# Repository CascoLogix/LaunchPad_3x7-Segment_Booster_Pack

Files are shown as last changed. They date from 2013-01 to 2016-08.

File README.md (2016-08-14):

# LaunchPad_3x7-Segment_Booster_Pack

#Description
This is just a simple 3x7-segment display that can be plugged into the TI MSP430 

#Background Info
I wanted to make my own 7-segment LED display booster pack for the LaunchPad that doesn't use a display driver IC, such as the CD4056BE, or SN7446A. In other words, I wanted to be in control of the firmware to perform driving the segments of each digit and performing the digit scanning function. 
So, I came up with this nifty little board - very simple. It includes a buffer driver IC, since the MSP430 IO pins are not rated to drive this much current in total. 
It was also a learning exercise, in that it was the first project where I used KiCAD's EDA software to learn all the ins and outs of creating schematic decals, PCB footprints, working with the component library interface, maping the schematic decals to the PCB footprints. And for the finishing touch, using Wings3D for creating the solid rendering of the boards. It was fun, easy, and it worked and I learned a lot in the process. 
Checkout the video in the links section below to see it in action!

#Links
##CascoLogix Product Page:
http://www.cascologix.com/store/p3/LaunchPad%C2%A03x7-segment_Booster_Pack.html
##Tindie Product Page:
https://www.tindie.com/products/CascoLogix/msp430-launchpad-3x7-segment-booster-pack/
##Hackaday Project Page:
https://hackaday.io/project/1779-launchpad-3x7-segment-display-booster-pack
##OSHPark PCB Page
https://oshpark.com/shared_projects/FeiOSTLi
##Video
https://www.youtube.com/watch?v=f7Dp6MClfQ0

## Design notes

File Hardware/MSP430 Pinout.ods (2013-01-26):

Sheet: MSP430F2112_28TSSOP
 | MSP430F2112IPWR
Pin# | Primary Name | Alternate Function | Signal Name
1 | TEST/SBWTCK |  | SBWTCK
2 | DVCC |  | 3.3V
3 | P2.5/Rosc/CA5
4 | DVSS |  | GND
5 | XOUT/P2.7/CA7
6 | XIN/P2.6/CA6
7 | RST/NMI/SBWTDIO |  | SBWTDIO
8 | P2.0/ACLK/A0/CA2 |  | DA_0
9 | P2.1/TAINCLK/SMCLK/A1/CA3 |  | DA_1
10 | P2.2/TA0.0/A2/CA4/CAOUT |  | DA_2
11 | P3.0/UCB0STE/UCA0CLK/A5 |  | SPI_CLK
12 | P3.1/UCB0SIMO/UCB0SDA |  | I2C_SDA
13 | P3.2/UCB0SOMI/UCB0SCL |  | I2C_SCL
14 | P3.3/UCB0CLK/UCA0STE |  | SPI_CS
15 | P3.4/UCA0TXD/UCA0SIMO |  | SPI_SIMO
16 | P3.5/UCA0RXD/UCA0SOMI |  | SPI_SOMI
17 | P3.6/TA1.0/A6
18 | P3.7/TA1.1/A7
19 | P2.3/TA0.1/A3/V /Ve /CA0
20 | P2.4/TA0.2/A4/V /Ve /CA1
21 | P1.0/TACLK/ADC10CLK/CAOUT |  | SEG_A
22 | P1.1/TA0.0/TA1.0 |  | SEG_B
23 | P1.2/TA0.1 |  | SEG_C
24 | P1.3/TA0.2 |  | SEG_D
25 | P1.4/SMCLK/TCK |  | SEG_E
26 | P1.5/TA0.0/TMS |  | SEG_F
27 | P1.6/TA0.1/TDI/TCLK |  | SEG_G
28 | P1.7/TA0.2/TDO/TDI |  | SEG_DP

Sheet: MSP430F2112_32VQFN
 | MSP430F2112IRHBR
Pin# | Primary Name | Alternate Function | Signal Name
1 | DVSS |  | GND
2 | XOUT/P2.7/CA7
3 | XIN/P2.6/CA6
4 | NC
5 | RST/NMI/SBWTDIO |  | SBWTDIO
6 | P2.0/ACLK/A0/CA2 |  | DA_0
7 | P2.1/TAINCLK/SMCLK/A1/CA3 |  | DA_1
8 | P2.2/TA0.0/A2/CA4/CAOUT |  | DA_2
9 | P3.0/UCB0STE/UCA0CLK/A5 |  | SPI_CLK
10 | P3.1/UCB0SIMO/UCB0SDA |  | I2C_SDA
11 | P3.2/UCB0SOMI/UCB0SCL |  | I2C_SCL
12 | P3.3/UCB0CLK/UCA0STE |  | SPI_CS
13 | P3.4/UCA0TXD/UCA0SIMO |  | SPI_SIMO
14 | P3.5/UCA0RXD/UCA0SOMI |  | SPI_SOMI
15 | P3.6/TA1.0/A6
16 | P3.7/TA1.1/A7
17 | NC
18 | P2.3/TA0.1/A3/V /Ve /CA0
19 | P2.4/TA0.2/A4/V /Ve /CA1
20 | NC
21 | P1.0/TACLK/ADC10CLK/CAOUT |  | SEG_A
22 | P1.1/TA0.0/TA1.0 |  | SEG_B
23 | P1.2/TA0.1 |  | SEG_C
24 | P1.3/TA0.2 |  | SEG_D
25 | P1.4/SMCLK/TCK |  | SEG_E
26 | P1.5/TA0.0/TMS |  | SEG_F
27 | P1.6/TA0.1/TDI/TCLK |  | SEG_G
28 | P1.7/TA0.2/TDO/TDI |  | SEG_DP
29 | TEST/SBWTCK |  | SBWTCK
30 | DVCC |  | 3.3V
31 | NC
32 | P2.5/R /CA5

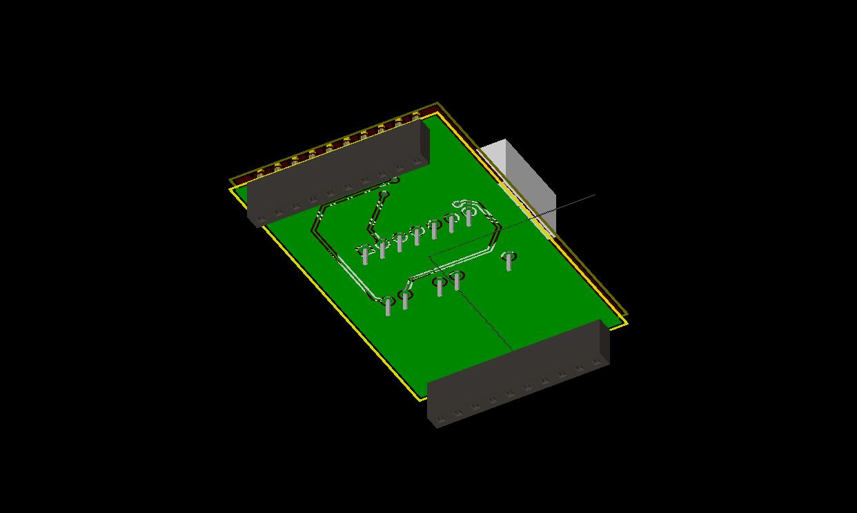
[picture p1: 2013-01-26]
Rendered_Pics/LaunchPad_3x7-Segment_Display_Booster_Pack_Isometric_Bottom.jpg

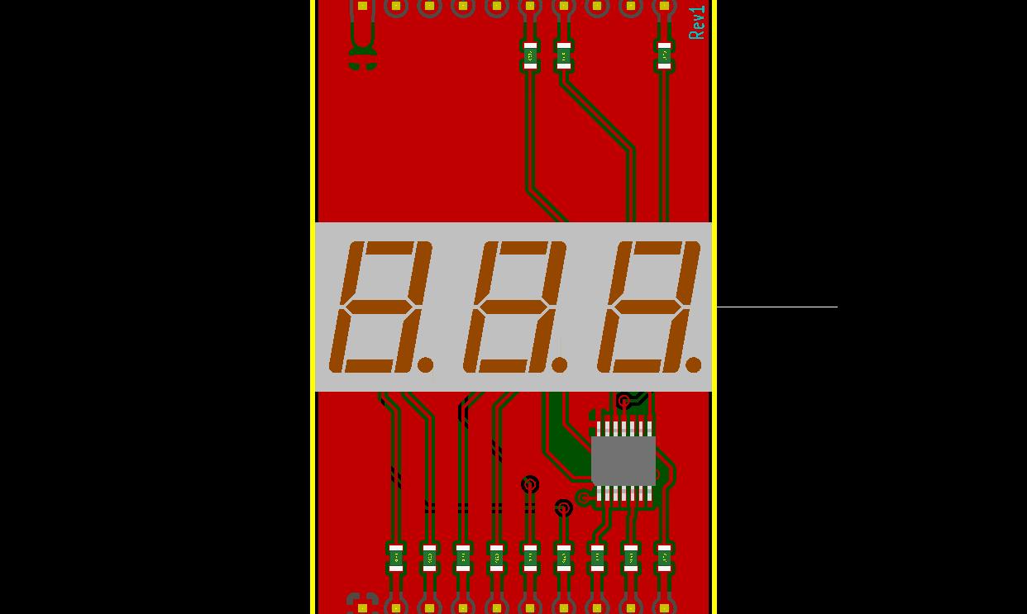
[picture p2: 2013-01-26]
Rendered_Pics/LaunchPad_3x7-Segment_Display_Booster_Pack_Top_90.jpg

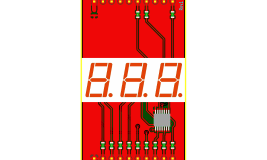
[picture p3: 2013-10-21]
Rendered_Pics/LaunchPad_3x7-Segment_Display_Booster_Pack_Top_90_Resized.png

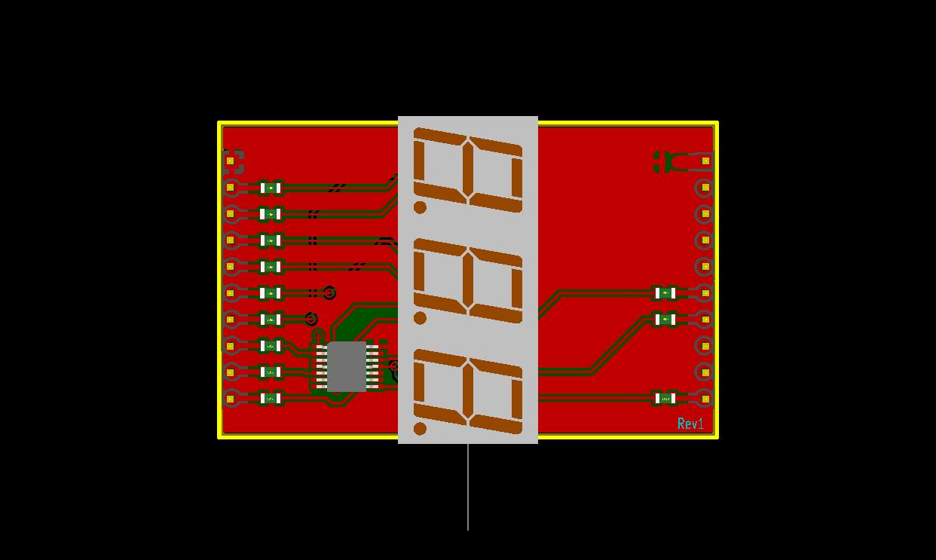
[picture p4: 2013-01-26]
Rendered_Pics/LaunchPad_3x7-Segment_Display_Booster_Pack_Top.jpg

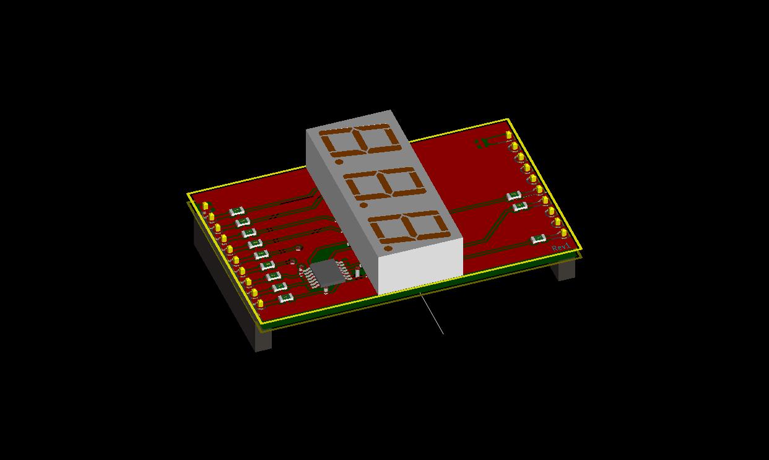
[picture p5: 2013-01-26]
Rendered_Pics/LaunchPad_3x7-Segment_Display_Booster_Pack_Isometric2.jpg

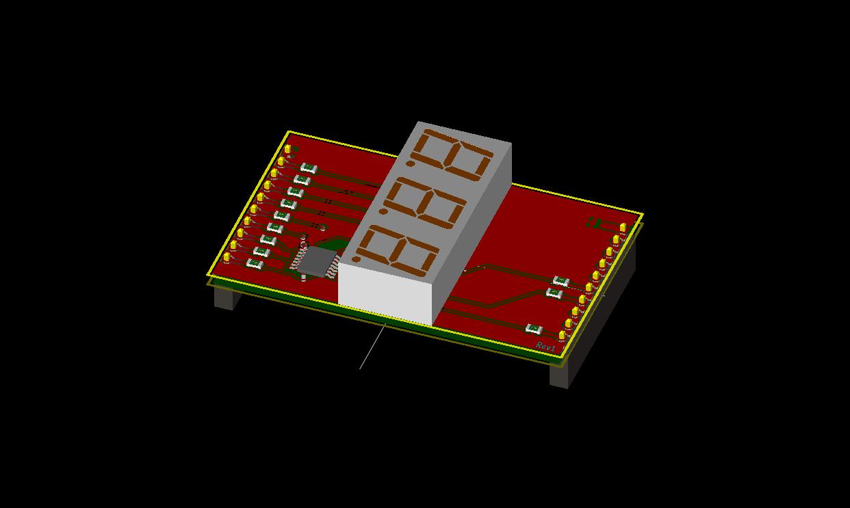
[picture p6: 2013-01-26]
Rendered_Pics/LaunchPad_3x7-Segment_Display_Booster_Pack_Isometric.jpg

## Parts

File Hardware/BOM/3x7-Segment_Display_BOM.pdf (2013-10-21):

Vendor | Vendor P/N | Mfg | Mfg P/N | Reference Designator | Qty | Description | Price Ea | Total
| | | | PCB | 1 | Printed Circuit Board | $3.80 | $3.80
Digi-Key | S7008-ND | Sullins Connector Solutions | PPTC101LFBN-RC | P1, P2 | 2 | CONN HEADER FEMALE 10POS.1" TIN | $0.83 | $1.66
Digi-Key | 568-2288-1-ND | Philips | 74LVC125APW,118 | U1 | 1 | IC BUFF DVR TRI-ST QD 14TSSOP | $0.46 | $0.46
Digi-Key | 311-100GRCT-ND | Yageo | RC0603JR-07100RL | R12,R11,R1 0,R9,R8,R7, R6,R5 | 8 | RES 100 OHM 1/10W 5% 0603 SMD | $0.01 | $0.10
Digi-Key | 311-1.0KGRCT-ND | Yageo | RC0603JR-071KL | R4,R3,R2,R 1 | 4 | RES 1.0K OHM 1/10W 5% 0603 SMD | $0.01 | $0.10
Digi-Key | 445-3448-1-ND | TDK Corporation | C1608Y5V0J106Z | C1 | 1 | CAP CER 10UF 6.3V Y5V 0603 | $0.42 | $0.42
Digi-Key | 160-1544-5-ND | Lite-On Inc | LTC-4624JR | U2 | 1 | LED 7-SEG .4" 3DGT SUPER RED CA | $3.24 | $3.24
| | | | | | | Total | $5.98

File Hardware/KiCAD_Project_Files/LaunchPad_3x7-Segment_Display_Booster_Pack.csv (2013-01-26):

ref | value | footprint
C1 | 10uF
P1 | HEADER_1X10
P2 | HEADER_1X10
R1 | RES
R2 | RES
R3 | RES
R4 | RES
R5 | RES
R6 | RES
R7 | RES
R8 | RES
R9 | RES
R10 | RES
R11 | RES
R12 | RES
U1 | 74LS125
U2 | LTC4624

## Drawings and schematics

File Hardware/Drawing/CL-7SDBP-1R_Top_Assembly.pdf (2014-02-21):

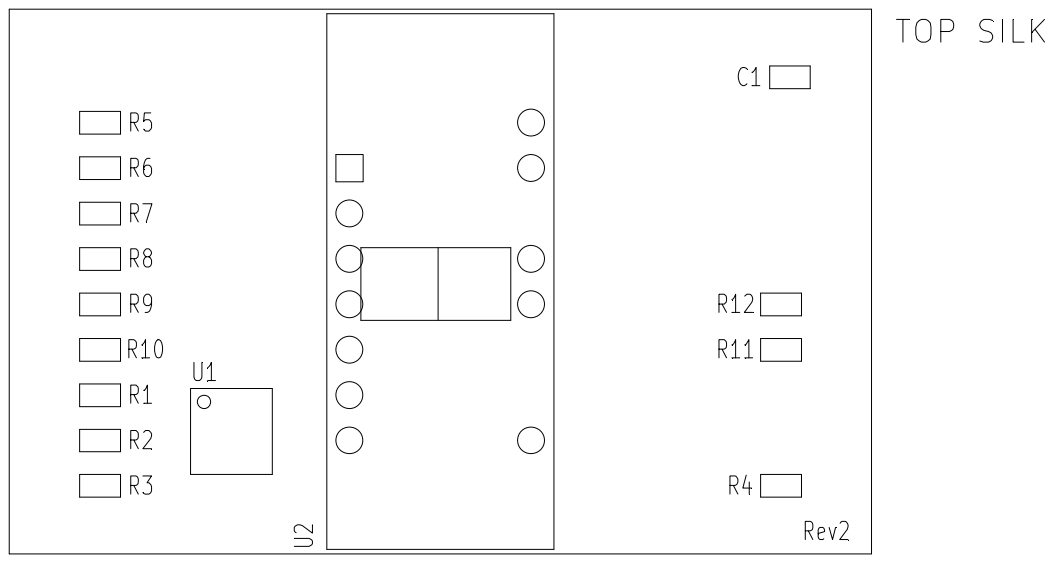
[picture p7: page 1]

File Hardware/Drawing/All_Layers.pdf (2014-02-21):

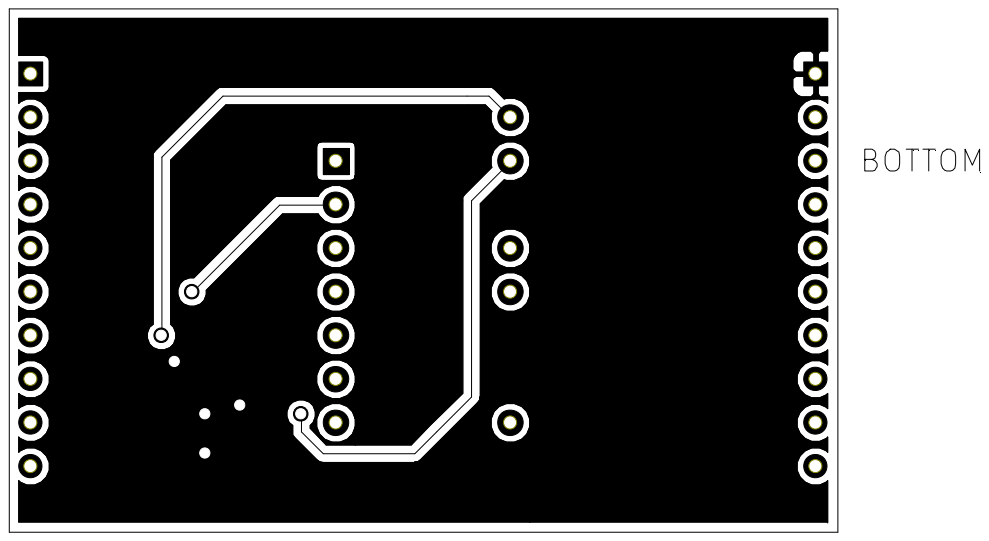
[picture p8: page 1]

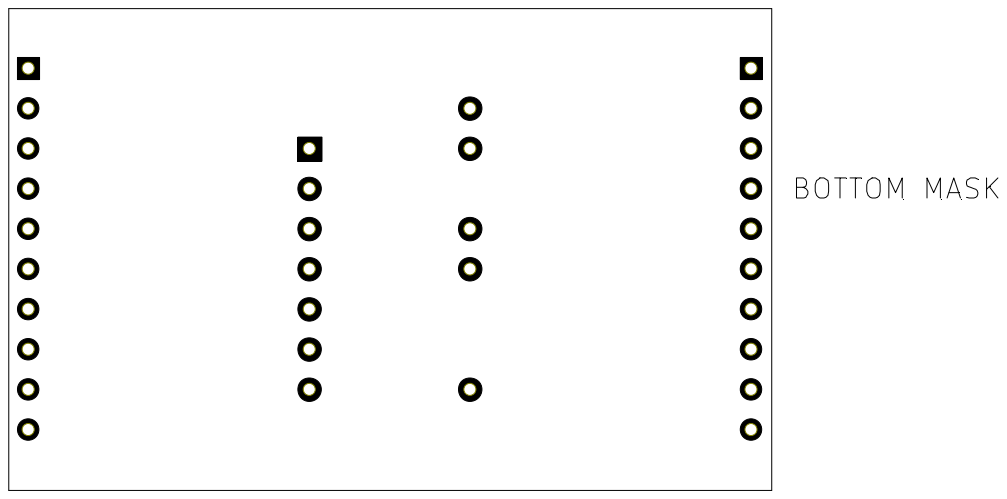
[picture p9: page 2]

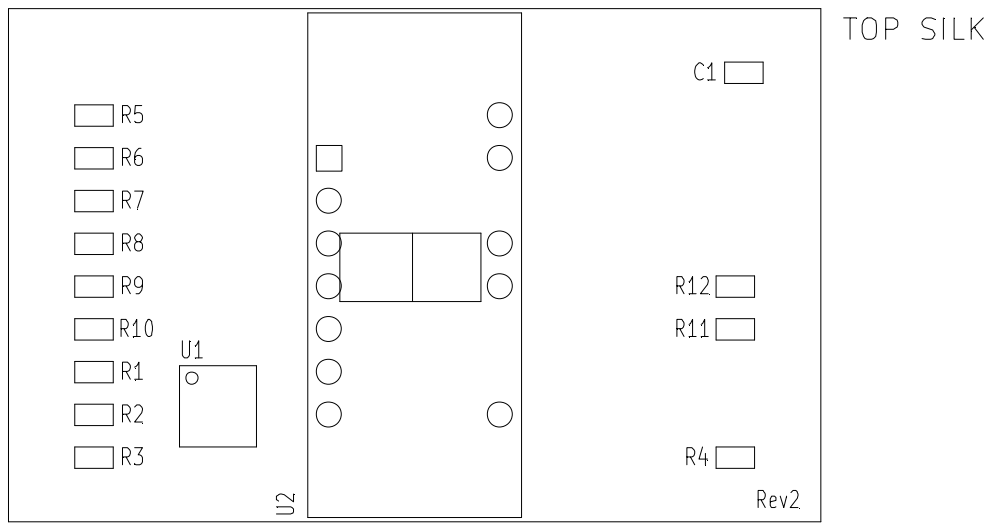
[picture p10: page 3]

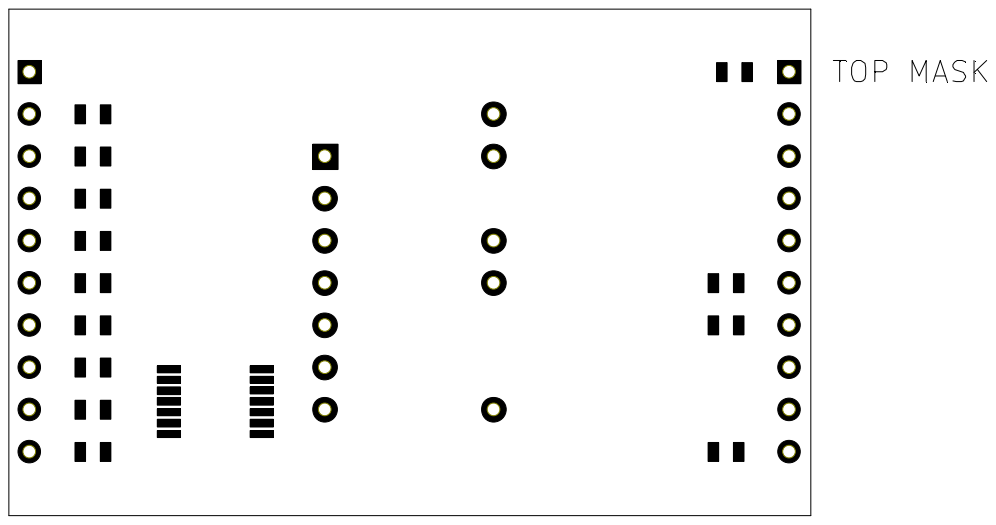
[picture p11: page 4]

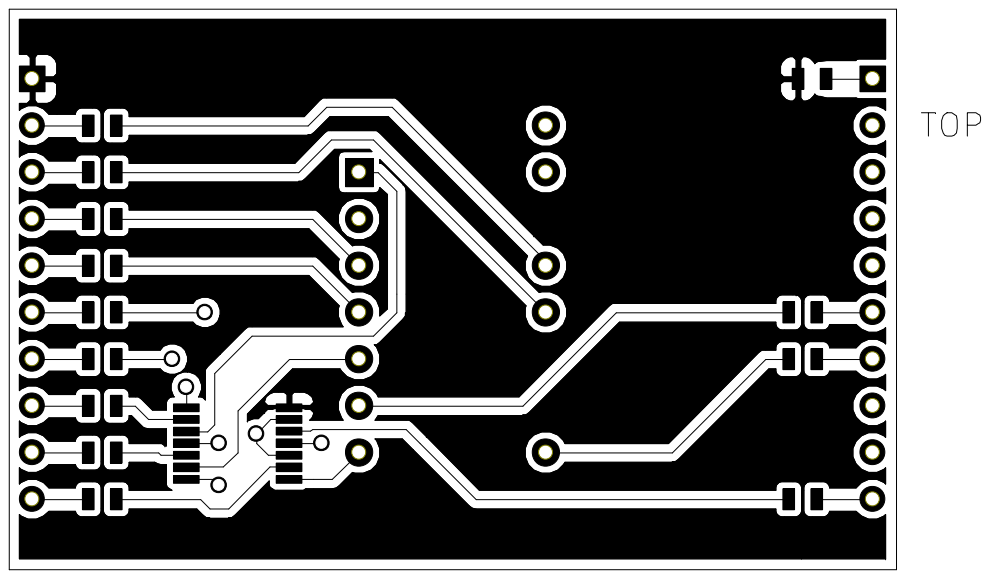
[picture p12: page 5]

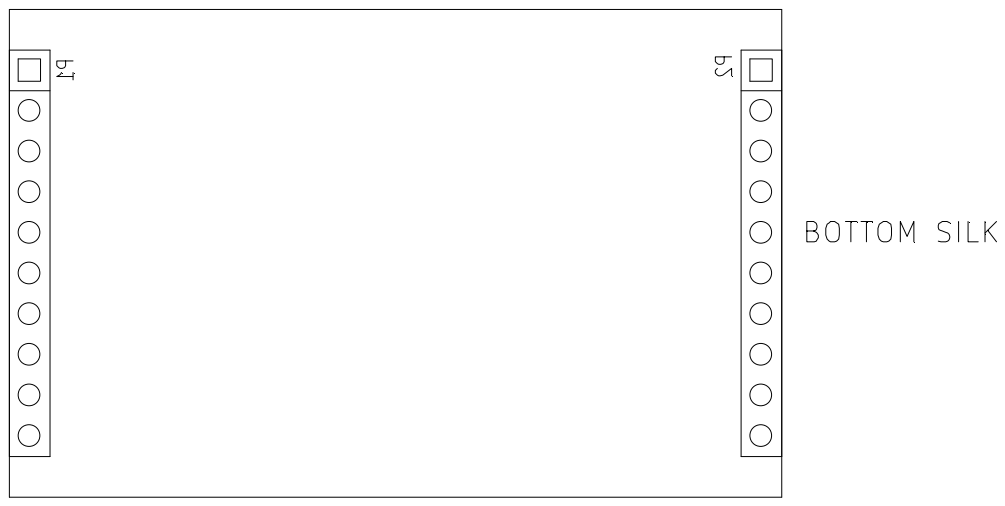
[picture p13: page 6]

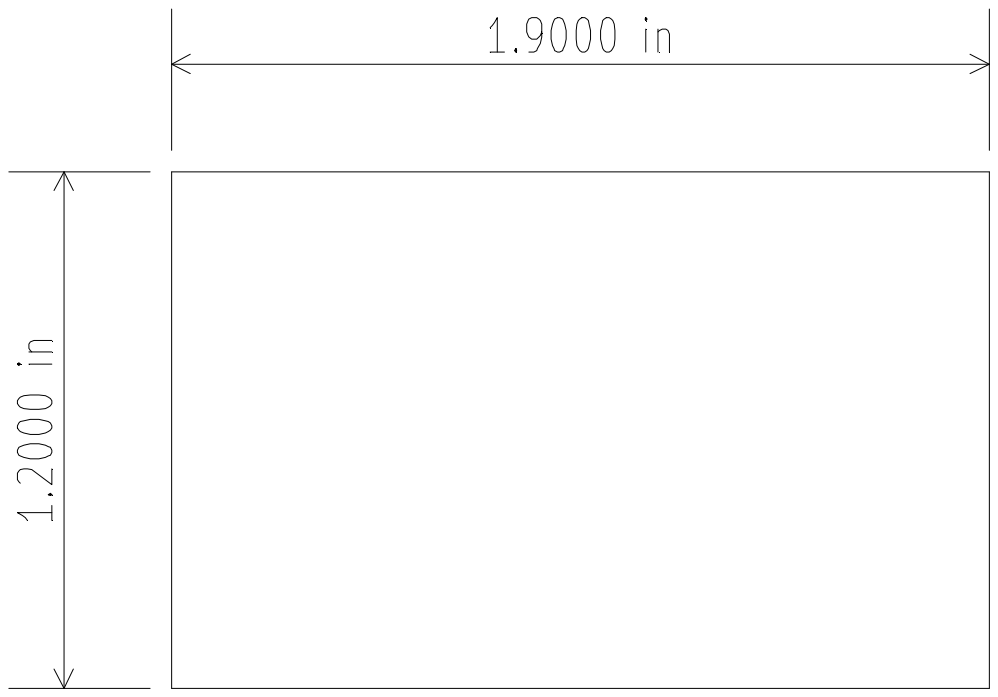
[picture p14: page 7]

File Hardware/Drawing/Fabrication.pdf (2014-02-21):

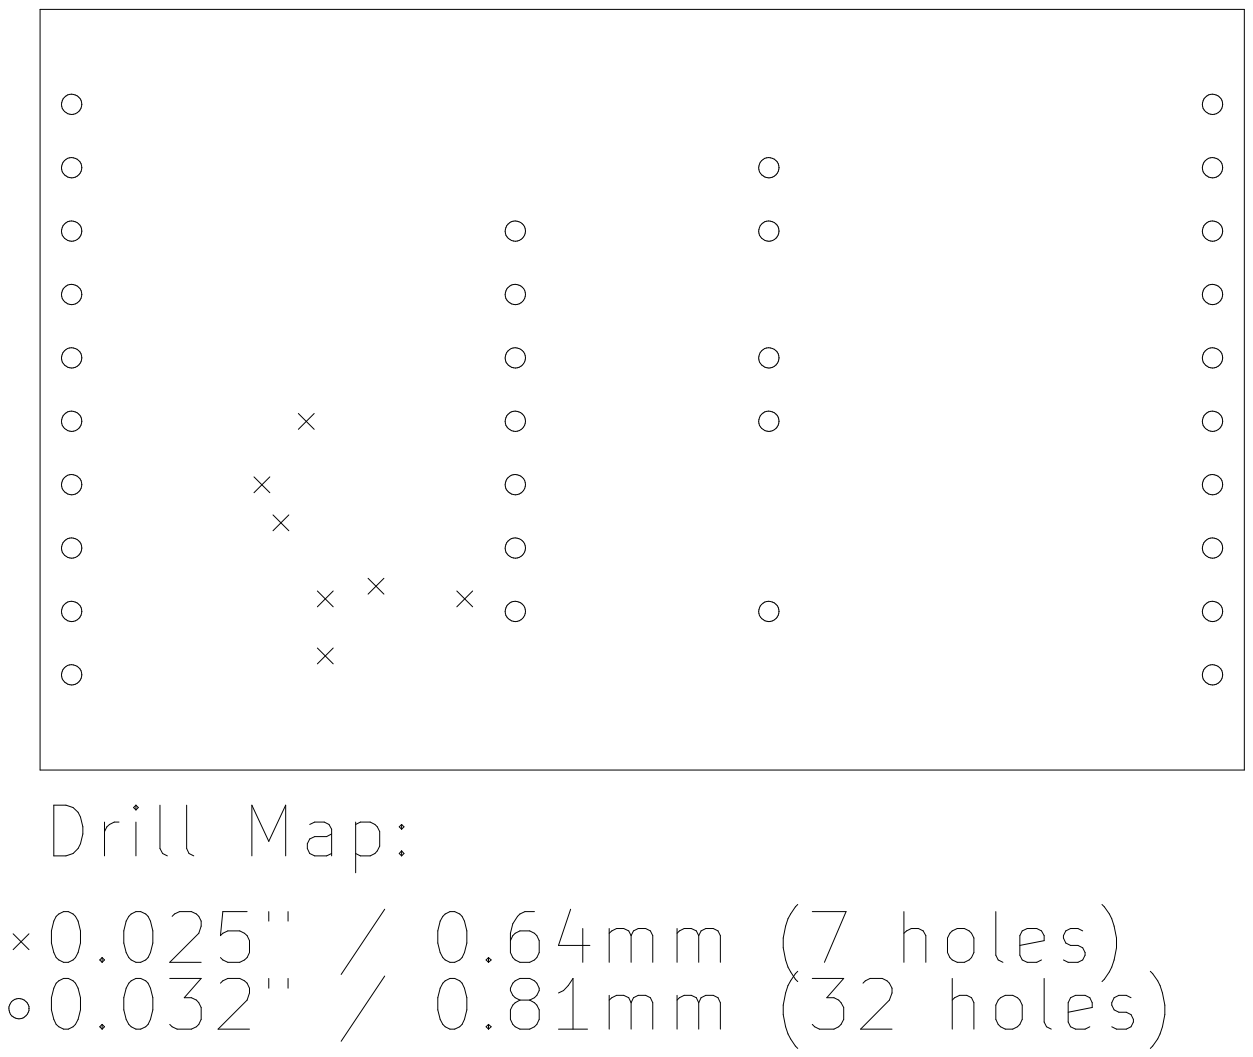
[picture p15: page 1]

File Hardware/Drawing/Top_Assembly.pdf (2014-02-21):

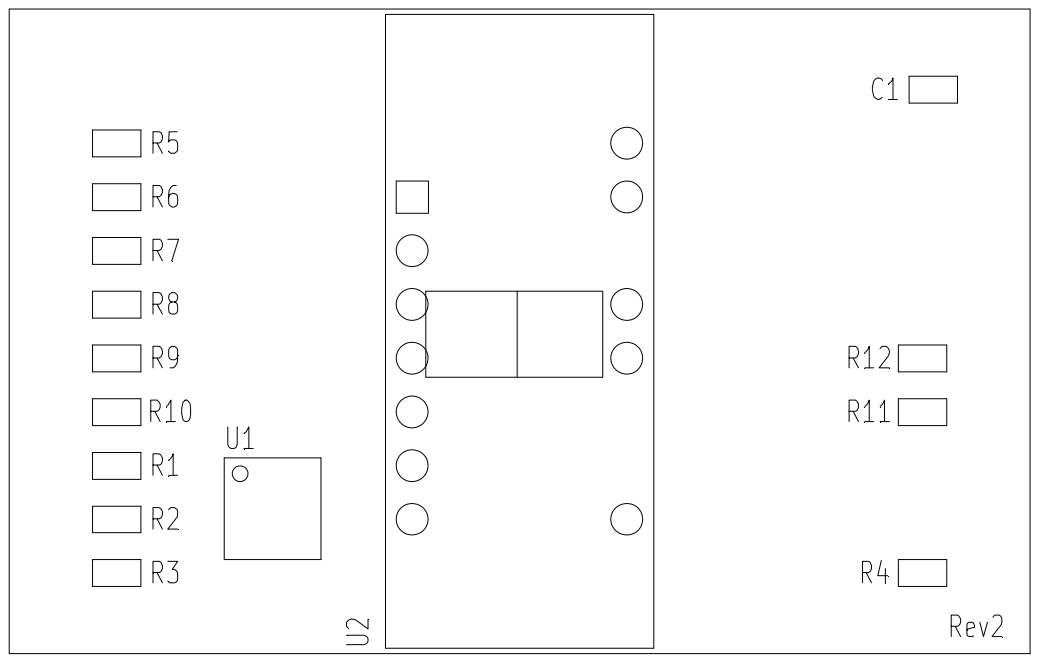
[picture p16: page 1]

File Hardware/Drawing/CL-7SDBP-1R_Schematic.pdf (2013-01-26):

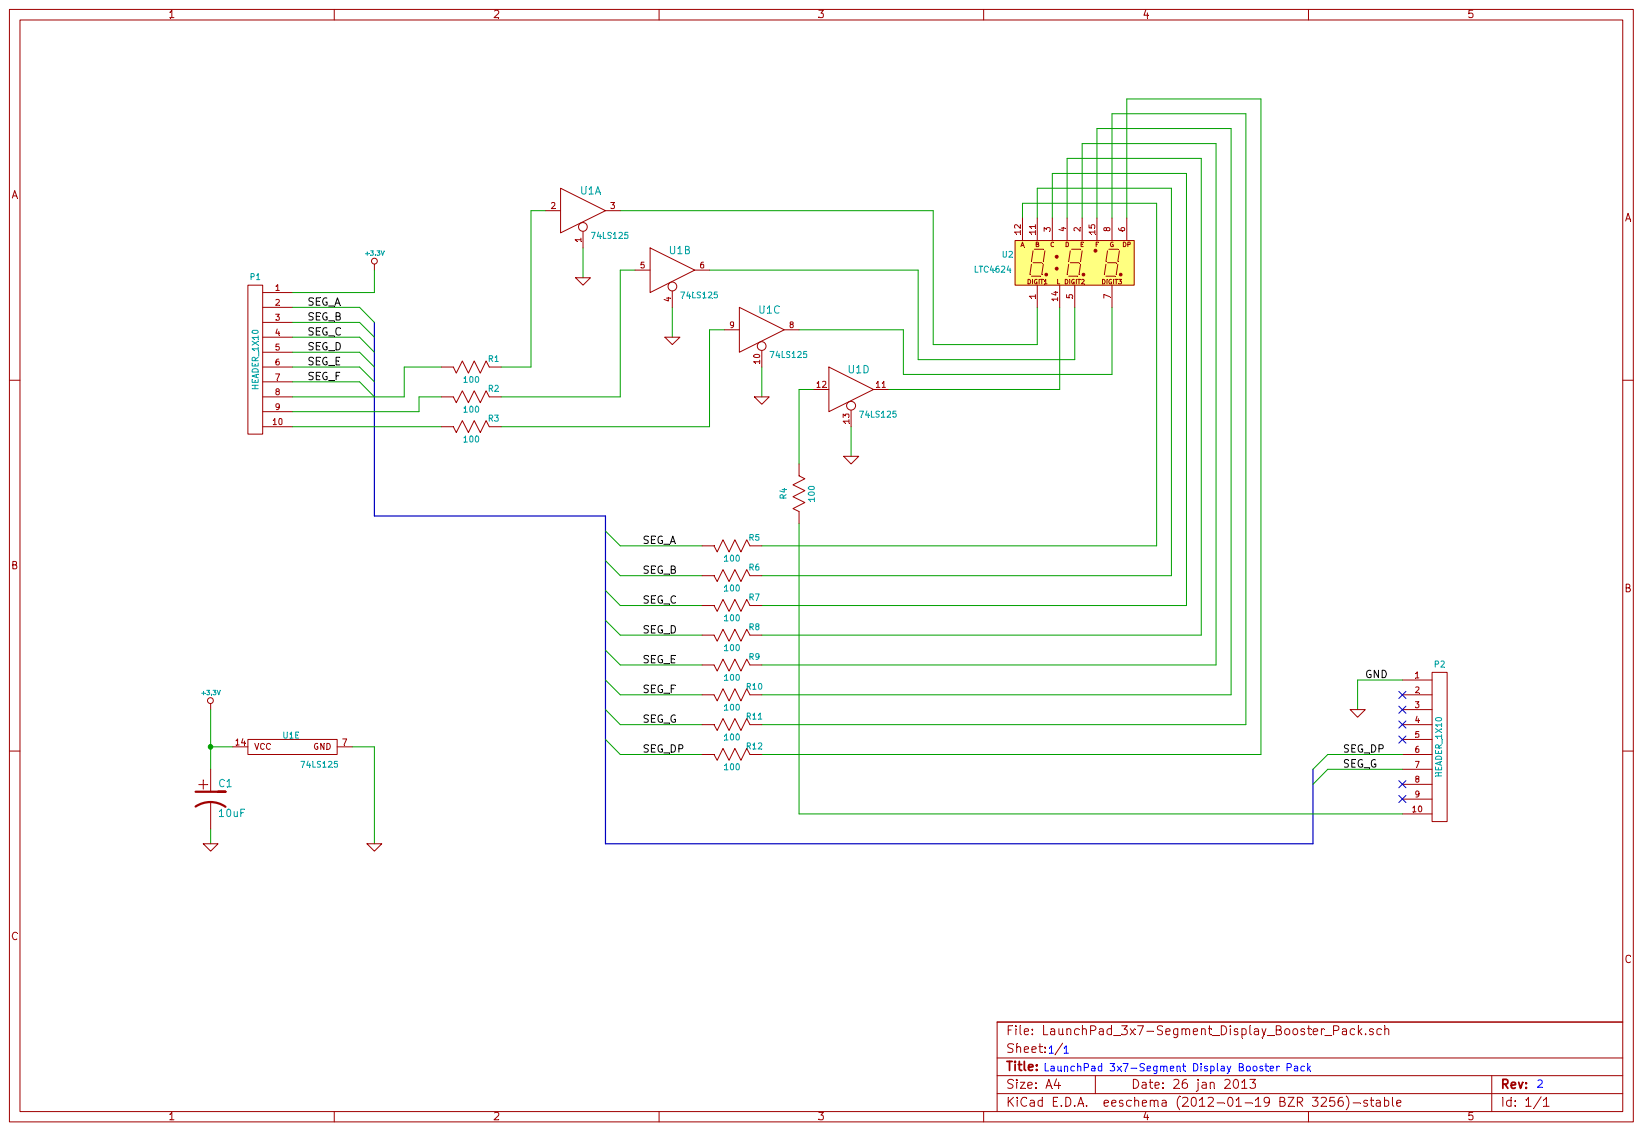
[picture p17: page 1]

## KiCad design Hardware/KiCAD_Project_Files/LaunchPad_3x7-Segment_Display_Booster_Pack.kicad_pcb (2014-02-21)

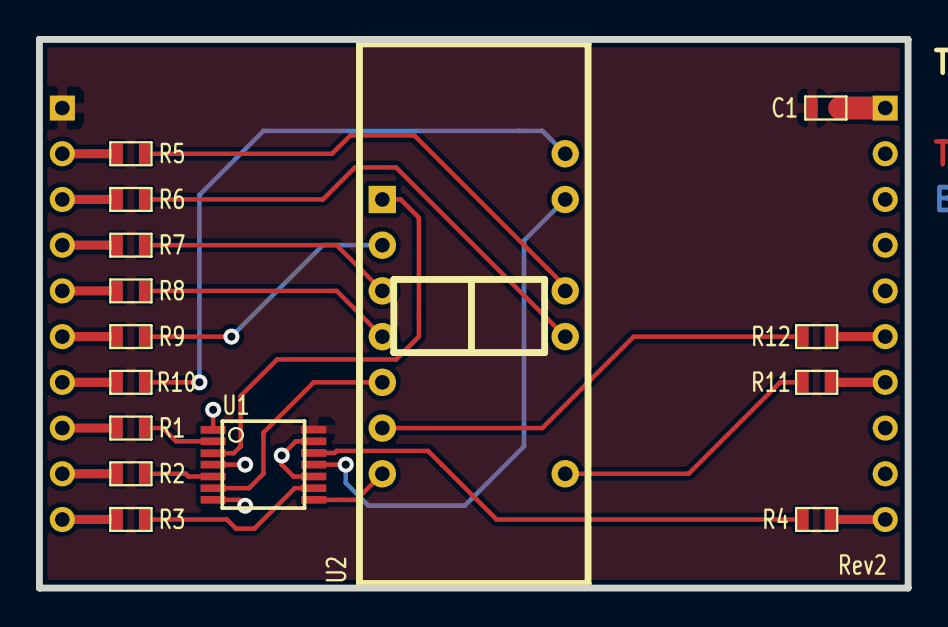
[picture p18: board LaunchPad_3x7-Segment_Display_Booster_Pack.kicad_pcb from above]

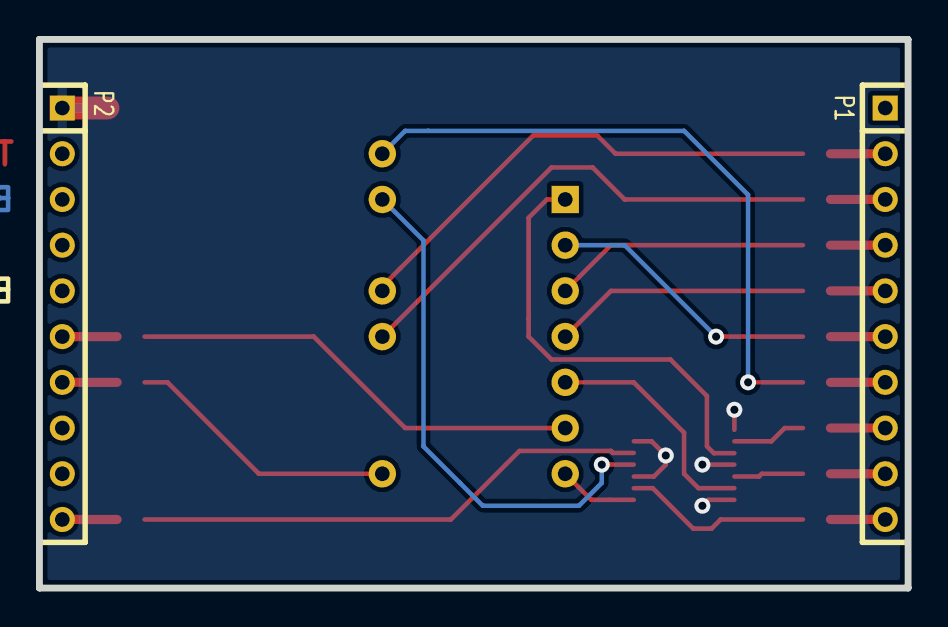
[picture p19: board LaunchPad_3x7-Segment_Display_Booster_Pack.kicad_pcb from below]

Board: 2 copper layers, 48.3 x 30.5 mm, 17 parts (2 on the bottom side), 30 nets.

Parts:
C1: 10uF; SM0603
P1, P2: HEADER_1X10; SIL-10
R1, R2, R3, R4, R5, R6, R7, R8, R9, R10, R11, R12: RES; SM0603
U1: 74LS125; SSOP14
U2: LTC4624; LTC4624JF

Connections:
+3.3V: C1.1, P1.1, U1.14
/SEG_A: P1.2, R5.2
/SEG_B: P1.3, R6.2
/SEG_C: P1.4, R7.2
/SEG_D: P1.5, R8.2
/SEG_DP: P2.6, R12.2
/SEG_E: P1.6, R9.2
/SEG_F: P1.7, R10.2
/SEG_G: P2.7, R11.2
GND: C1.2, P2.1, U1.1, U1.4, U1.7, U1.10, U1.13
unnamed: R1.1, U1.2
unnamed: R2.1, U1.5
unnamed: R3.1, U1.9
unnamed: P2.10, R4.1
unnamed: R5.1, U2.12
unnamed: R7.1, U2.3
unnamed: R9.1, U2.2
unnamed: R11.1, U2.8
unnamed: U1.11, U2.14
unnamed: R4.2, U1.12
unnamed: U1.8, U2.7
unnamed: U1.6, U2.5
unnamed: U1.3, U2.1
unnamed: R10.1, U2.15
unnamed: R8.1, U2.4
unnamed: R6.1, U2.11
unnamed: P1.8, R1.2
unnamed: P1.9, R2.2
unnamed: P1.10, R3.2
unnamed: R12.1, U2.6

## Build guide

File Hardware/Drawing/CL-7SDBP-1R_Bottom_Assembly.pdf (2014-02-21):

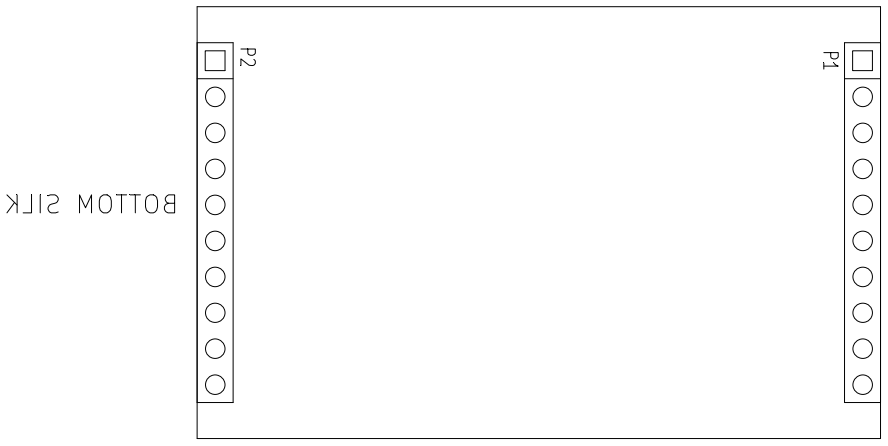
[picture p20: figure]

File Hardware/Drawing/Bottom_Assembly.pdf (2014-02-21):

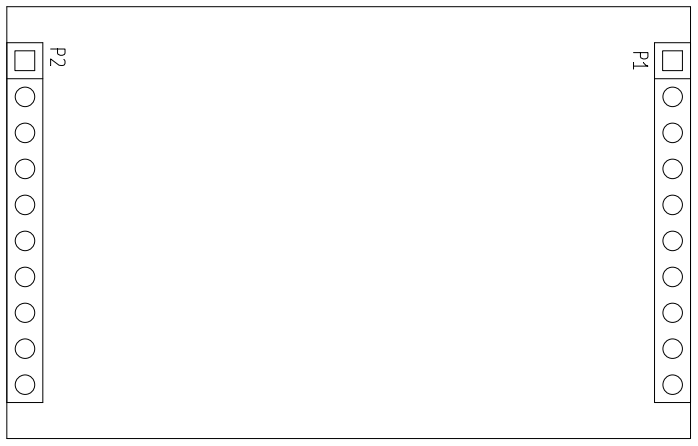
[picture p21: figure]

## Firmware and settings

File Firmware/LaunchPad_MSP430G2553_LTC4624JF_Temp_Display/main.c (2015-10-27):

#include <config.h>
#include <LTC4624JF.h>
#include <stdint.h>


#define ADCDeltaOn       3                  // ~ 2 Deg C delta for LED on


void initMSP430(void);
void kickstartADC10(void);


static unsigned int FirstADCVal;            // holds 1st ADC result
uint8_t display_Data[NUM_DIGITS];


void main(void)
{
	kickstartADC10();
	
   	WriteToDisplay(0, DIGIT_1);					// Initialize digit 1
   	WriteToDisplay(0, DIGIT_2);					// Initialize digit 2
   	WriteToDisplay(0, DIGIT_3);					// Initialize digit 3
   	WriteToDisplay(255, L_GROUP);
	initMSP430();
	_BIS_SR(LPM0_bits + GIE);					// Enter LPM0 w/ interrupt
}


void initMSP430(void)
{
	WDTCTL = WDTPW + WDTHOLD;					// Stop WDT
	
	P1DIR = 0xFF;								// P1.0 & P1.6 output
	P2DIR = BIT0|BIT1|BIT2|BIT3|BIT4|BIT5;		// P2.0 through P2.5 output
	
	TA1CCTL1 = CCIE;
	TA1CCR1 = DIGIT_TIME;
    BCSCTL2 |= DIVS0|DIVS1;						// Setup divider for SMCLK/8
	TA1CTL = TASSEL_2 + MC_2 + ID1;				// SMCLK, contmode
}


void kickstartADC10(void)
{
  WDTCTL = WDTPW + WDTHOLD;                 // Stop watchdog
  ADC10CTL1 = ADC10DIV_3 + INCH_10 + SHS_1 + CONSEQ_2;  // TA trig., rpt, A10
  ADC10CTL0 = SREF_1 + ADC10SHT_3 + REF2_5V + ADC10IE + REFON + ADC10ON;
  __enable_interrupt();                     // Enable interrupts.
  TA0CCR0 = 30;                             // Delay to allow Ref to settle
  TA0CCTL0 |= CCIE;                         // Compare-mode interrupt.
  TA0CTL = TASSEL_2 | MC_1;                 // TACLK = SMCLK, Up mode.
  LPM0;                                     // Wait for delay.
  TA0CCTL0 &= ~CCIE;                        // Disable timer Interrupt
  __disable_interrupt();
  ADC10CTL0 |= ENC;
  TA0CCTL1 = OUTMOD_4;                      // Toggle on EQU1 (TAR = 0)
  TA0CTL = TASSEL_2 + MC_2;                 // SMCLK, cont-mode
  while (!(ADC10IFG & ADC10CTL0));          // First conversion?
  FirstADCVal = ADC10MEM;                   // Read out 1st ADC value
  P1OUT = 0x00;                             // Clear P1
  P1DIR = 0x01;                             // P1.0 as output
}


#pragma vector=ADC10_VECTOR
__interrupt void ADC10_ISR (void)
{
  if (ADC10MEM >= FirstADCVal + ADCDeltaOn)
    P1OUT |= 0x01;                          // LED on
  else
    P1OUT &= ~0x01;                         // LED off
    
  WriteToDisplay((ADC10MEM & 0x0F), DIGIT_3);
  
  if(ADC10MEM > 15)
	WriteToDisplay(((ADC10MEM >> 4) & 0x0F), DIGIT_2);
  else
    ClearAnode(DIGIT_2);
    
  if(ADC10MEM > 255)
	WriteToDisplay(((ADC10MEM >> 8) & 0x0F), DIGIT_1);
  else
    ClearAnode(DIGIT_1);
}


#pragma vector=TIMER0_A0_VECTOR
__interrupt void ta0_isr(void)
{
  TA0CTL = 0;
  LPM0_EXIT;                                // Exit LPM0 on return
}


// Timer A0 interrupt service routine
//#pragma vector=TIMERA1_VECTOR		// MSP430F2618
#pragma vector=TIMER1_A1_VECTOR		// MSP430G2452, MSP430G2553
__interrupt void TimerA_CCR1 (void)
{
	switch(TA1IV)
	{
		case  2:                          		// CCR1
		{
    		DisplaySegments();
			TA1CCR1 += DIGIT_TIME;
			break;
		}
			
		case  4: 
			break;                          	// CCR2 not used
		
		case 10: 								// overflow
            break;
	}
}

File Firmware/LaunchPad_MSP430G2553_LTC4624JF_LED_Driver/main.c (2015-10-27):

#include <config.h>
#include <LTC4624JF.h>
#include <stdint.h>


void initMSP430(void);


extern void DisplaySegments(void);
extern void WriteToDisplay(uint8_t alphaNumeric, uint8_t anode);
extern void TestDisplay(void);
extern void ClearDisplay(void);
extern void TestAnode(uint8_t anode);
extern void ClearAnode(uint8_t anode);


uint8_t sec, min;
uint8_t display_Data[NUM_DIGITS];


void main(void)
{
	sec = 0;									// Initialize sec to 0
	min = 0;									// Initialize min to 0
   	WriteToDisplay(0, DIGIT_1);					// Initialize digit 1
   	WriteToDisplay(0, DIGIT_2);					// Initialize digit 2
   	WriteToDisplay(0, DIGIT_3);					// Initialize digit 3
   	WriteToDisplay(':', L_GROUP);				// Display colon
	initMSP430();
	_BIS_SR(LPM0_bits + GIE);					// Enter LPM0 w/ interrupt
}


void initMSP430(void)
{
	WDTCTL = WDTPW + WDTHOLD;					// Stop WDT
	
	P1DIR = 0xFF;								// P1.0 & P1.6 output
	P2DIR = BIT0|BIT1|BIT2|BIT3|BIT4|BIT5;		// P2.0 through P2.5 output
	
	TACCTL0 = CCIE;								// CCR0 interrupt enabled
	TACCTL1 = CCIE;
	TACCR0 = ONE_SECOND;
	TACCR1 = DIGIT_TIME;
    BCSCTL2 |= DIVS0|DIVS1;						// Setup divider for SMCLK/8
	//TACTL = TASSEL_2 + MC_2;					// SMCLK, contmode
	TACTL = TASSEL_2 + MC_2 + ID1;				// SMCLK, contmode
}


// Timer A0 interrupt service routine
//#pragma vector=TIMERA0_VECTOR		// MSP430F2618
#pragma vector=TIMER0_A0_VECTOR		// MSP430G2452, MSP430G2553
__interrupt void Timer_A_CCR0 (void)
{
    if (++sec > 59)						//count seconds, up to one minute
    {
        sec = 0;                        //reset seconds and ...
        if (++min > 9)					//count miutes, up to one hour
            min = 0;                    //reset minutes and ...
    }
    
    display_Data[DIGIT_3] = sec%10;
    display_Data[DIGIT_2] = sec/10;
    display_Data[DIGIT_1] = min;
    
    uint8_t i;
    
    for(i = 0; i < NUM_DIGITS; i++)
    	WriteToDisplay(display_Data[i], i);
    
    TACCR0 += ONE_SECOND;						// Setup next IRQ

}


// Timer A0 interrupt service routine
//#pragma vector=TIMERA1_VECTOR		// MSP430F2618
#pragma vector=TIMER0_A1_VECTOR		// MSP430G2452, MSP430G2553
__interrupt void TimerA_CCR1 (void)
{
	switch(TA0IV)
	{
		case  2:                          		// CCR1
		{
    		DisplaySegments();
			TACCR1 += DIGIT_TIME;
			break;
		}
			
		case  4: 
			break;                          	// CCR2 not used
		
		case 10: 								// overflow
            break;
	}
}

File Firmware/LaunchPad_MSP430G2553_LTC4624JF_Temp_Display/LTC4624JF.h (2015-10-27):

#ifndef LTC4624JF_H_
#define LTC4624JF_H_


// Includes
#include <config.h>
#include <stdint.h>


// Defines
#define _COMMON_ANODE_

#define NUM_DIGITS 		3
#define NUM_ANODES		4

#define MAX_DECIMAL		10
#define MAX_HEXADECIMAL	16

#define ANODE_1			0
#define ANODE_2			1
#define ANODE_3			2
#define ANODE_4			3

#define DIGIT_1			ANODE_1
#define DIGIT_2			ANODE_2
#define DIGIT_3			ANODE_3
#define L_GROUP			ANODE_4

#define SEG_A			(1 << 0)
#define SEG_B			(1 << 1)
#define SEG_C			(1 << 2)
#define SEG_D			(1 << 3)
#define SEG_E			(1 << 4)
#define SEG_F			(1 << 5)
#define SEG_G			(1 << 6)
#define SEG_DP			(1 << 7)

#define SEG_L1			SEG_A
#define SEG_L2			SEG_B
#define SEG_L3			SEG_C


extern void WriteToDisplay(uint8_t alphaNumeric, uint8_t anode);
extern void TestDisplay(void);
extern void ClearDisplay(void);
extern void TestAnode(uint8_t anode);
extern void ClearAnode(uint8_t anode);
extern void DisplaySegments(void);
extern uint8_t DecimalNumLookup(uint8_t number);
extern uint8_t HexNumLookup(uint8_t number);
extern uint8_t AlphaLookup(char ascii);
extern void DPOn(uint8_t anode);
extern void DPOff(uint8_t anode);


extern uint8_t codedDataArray[NUM_ANODES];				// stores the active segments for each digit
extern uint8_t anode;									// local variable to select which anode is active
extern uint8_t testMode;								// local flag to activate/deactivate test mode


#endif /*LTC4624JF_H_*/

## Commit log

2013-01-26 First commit.
    [LaunchPad_3x7-Segment_Display_Booster_Pack.brd, LaunchPad_3x7-Segment_Display_Booster_Pack.csv, LaunchPad_3x7-Segment_Display_Booster_Pack.sch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]
2013-01-26 Updated to current board design
    [LaunchPad_3x7-Segment_Display_Booster_Pack.brd, LaunchPad_3x7-Segment_Display_Booster_Pack.csv, LaunchPad_3x7-Segment_Display_Booster_Pack.sch]
2013-01-26 Reorganized directory to move gerber directory where it belongs.
2013-01-26 Updated resistor component values on schematic Updated pdf of schematic Created new gerber files to the gerber directory
    [LaunchPad_3x7-Segment_Display_Booster_Pack.brd]
2013-01-26 Corrected board to show Rev2 (previous check-in showed Rev1). Regenerated new gerbers with Rev2 artwork. Added rendered pictures of PCB assembly
    [LaunchPad_3x7-Segment_Display_Booster_Pack.brd]
2013-01-26 Renamed gerber archive to include "Gerbers" in the filename
2013-10-21 Updated to new kicad board format. + Rendered pic + pdf of BOM
    Minor corrections to schematic.
    [LaunchPad_3x7-Segment_Display_Booster_Pack.brd, LaunchPad_3x7-Segment_Display_Booster_Pack.sch]
2013-11-03 Added gerbers for OSH Park and re-structured gerber file folders
    [LaunchPad_3x7-Segment_Display_Booster_Pack-Back.gbl, LaunchPad_3x7-Segment_Display_Booster_Pack-Front.gtl, LaunchPad_3x7-Segment_Display_Booster_Pack-Mask_Back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]
2013-12-04 Minor changes to schematic due to updtaed female header decal. Updated sheet size to standard 8.5x11. Moved BOM's and Schematic into respective folders to conform to newer project directory structure.
    [LaunchPad_3x7-Segment_Display_Booster_Pack.sch]
2014-02-21 Added new kicad pcb file formats. Added layer identification text to each layer. Added pdf's of layout, assembly, and fabrication
    [LaunchPad_3x7-Segment_Display_Booster_Pack.kicad_pcb]
2014-02-21 Added separate Top and Bottom Assembly drawings. Updated board renders to have transparent background.
2015-10-27 Added LTC4624JF.h and LTC4624JF.c files and example CCS projects. Removed old gerber files and other old files.
    [LaunchPad_3x7-Segment_Display_Booster_Pack-Back.gbl, LaunchPad_3x7-Segment_Display_Booster_Pack-Front.gtl, LaunchPad_3x7-Segment_Display_Booster_Pack-Mask_Back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]
